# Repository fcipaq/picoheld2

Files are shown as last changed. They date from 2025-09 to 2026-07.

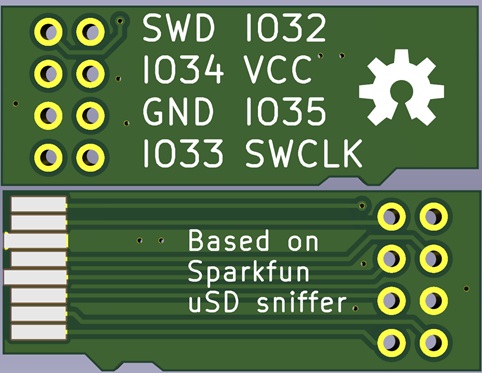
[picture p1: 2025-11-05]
pcb/rp2350/usd breakout board/uSD breakout board image.jpg

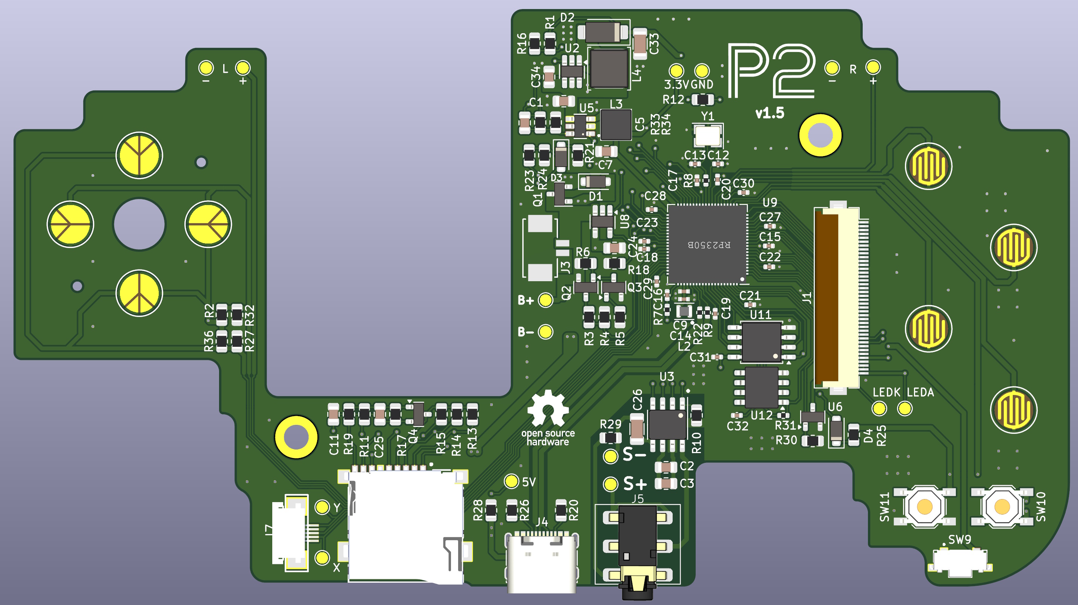
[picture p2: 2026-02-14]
pcb/rp2350/mainboard/p2_pcb_rp2350_v1_5_image.jpg

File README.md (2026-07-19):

# Pico Held 2 hardware resources

This site is all about the Pico Held 2's hardware: schematics, 3D design files, gerber files for PCB production, component specifications and so on.

DISCLAIMER: This is a DIY project. Do it at your own risk. I cannot be held responsible for anything that goes wrong, including design errors. I'm not doing this for profit – I'm just a guy sharing a hobby project.

## Obtaining the hardware as a kit

It's probably the cheapest solution if you buy everything as a bundle from me. I bought them in bulk to save on shipping costs. I sell a "kit" on eBay. It contains the mainboard (including the MCU), shoulder button PCBs, LCD, rubber pads, screws, speaker. However, you will still need the 3D-printed parts (case, start/select buttons, and shoulder buttons), the SNES buttons, the analog stick and the battery.
Since I'm not running a business and don't intend to, if you want to buy a kit, drop me an email (daniel.kammer@web.de) and I'll create an offer on eBay and send you the link (if I can ship to your country that is). The kit costs around 80 Euros.

## Notes on assembly

You can find an assembly video [here](https://www.youtube.com/watch?v=lgt-NjA-OhY).

Please watch the video to see if you are able to do it before making any purchases. Unfortunately, I cannot be held responsible if anything goes wrong. I'm not doing this for profit; I'm just a guy sharing a hobby project.

### parts

If you want to buy everything by yourself, you can find info/links about the parts here:

[LCD](https://aliexpress.com/item/1005007751423312.html) (ESP32-P4)

[LCD](https://aliexpress.com/item/1005008256444774.html) (RP2350)

[Speaker](https://aliexpress.com/item/1005004431389186.html)

For all other parts, see parts.txt in the assembly folder.

All parts for the PCB assembly can be found in the BOM lists in the pcb subfolder.

### 3D case

The 3D printed case features holding brackets for the LCD, holding the LCD tightly in place. Since the overall height has increased, you need to fiddle around a little bit with the rubber pads of the buttons (since the buttons are still the same height). You'll probably get the best results if you glue the rubber pads to the buttons so they won't slip. Tolerances are sometimes off, so using sandpaper may be necessary. There are threaded inserts for the screws required that you'll have to hammer innto the case. I can provide these in the kit, just let me know.
Using the printed version is at your own risk - I just do not have the resources to test is as thoroghly as I did with aluminum case. Since I did all the optimization for the aluminum shell, however, find the platic case to be more comfotable since it's a little thicker

## Software

For quick testing, the repos usually contain a folder called 'artifacts', which contains a file ready to be uploaded to the device.

### Flashing

To enter bootloader mode on both versions, do the following: Press SELECT (left key), then hold down START (right key). You can then release SELECT, but you need to keep START pressed. Releasing the START button will shut down the device and interrupt any ongoing data upload.
If anything goes wrong, you can always press the reset button (located behind the tiny hole on the bottom of the device) and start again.

### RP2350 version

[SNES emulator](https://github.com/fcipaq/picoheld2_rp2350_snes9x)

[Hardware engine](https://github.com/fcipaq/picoengine) (to create your own projects)

### ESP32-P4 version

[SNES emulator](https://github.com/fcipaq/snes9x_esp32)

[Quake](https://github.com/fcipaq/esp32-quake-p2)

[Retro-Go](https://github.com/fcipaq/esp32-quake-p2) (various retro emulators, WIP)

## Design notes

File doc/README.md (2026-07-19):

TODO

In case you want to pick a different display for the RP2350, be advised that some display are unable to change the gate driver scan direction so that the image will be flipped.

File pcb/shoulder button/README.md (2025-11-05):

This is the PCB for the shoulder buttons. You will (obviously) need two of them :)

The thickness is 1.6 mm

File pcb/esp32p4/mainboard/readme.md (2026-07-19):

These are the gerber files, schematics and BOM and CPL files for the mainboard (ESP32-P4 version)

!!! When manually installing the ESP32-P4-SOM, pay close attention to its orientation. Some versions have a dot imprint on the metal shell that can be misleading because it does NOT indicate pin 0.
IMPORTANT: The orientation of the SOM is correctly depicted in the image. Counterintuitively, the circular dent in the SOM's cover must not be aligned with the dot on the PCB (the SOM manufacturer may change that in the future)

The PCB thickness is 1.6 mm

The BOM and CPL files are in xlsx format ready to be manufactured at JLCPCB. I already checked the alignment. Unfortunately, some components are unavailable in JLC's parts library.

The JPG image is for reference only and might not accurately reflect the current state.

The battery connector (J3) is pretty tall, so depending on the tolerances, it might bump against the LCD. You might want to consider omitting the connector and solder the battery directly to the PCB.

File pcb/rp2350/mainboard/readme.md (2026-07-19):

These are the gerber files, schematics, BOM and CPL files for the mainboard (RP2350 version)

The battery connector (J3) is pretty tall, so depending on the tolerances, it might bump against the LCD. You might want to consider omitting the connector and solder the battery directly to the PCB.

The PCB thickness is 1.6mm

The BOM and CPL files come in two versions:

a) PCBWay
b) for JLCPCB (in an xlsx format). I already checked the alignment. Unfortunately, some components are unavailable in JLC's parts library.

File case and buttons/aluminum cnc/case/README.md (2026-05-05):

Be sure to upload the specifications for the threaded holes along with the particular step file for CNC machining.

It's advised to have both parts manufactured in one order so the manufacturer can check tolerances and fit the color of the top and bottom part.

Remarks for the manufacturer:
The top and bottom peaces are sub assemblies and will be screwed together
Laser mark: 
Units in mm
The laser mark is ONLY "P2" centered on the back of the shell. (The other lines are for dimensional reference only)
The lines must be filled (only the outline is shown). The blue area is what has to actually be laser marked.

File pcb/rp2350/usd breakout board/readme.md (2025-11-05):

These are the gerber files for the micro SD breakout board which you need if you want to break out the debug pins and/or (SPI-)GPIOs.

The PCB thickness is 0.8 mm

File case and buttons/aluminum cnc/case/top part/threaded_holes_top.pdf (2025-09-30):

Threaded Holes

Type A:

4 threads, M 1.6

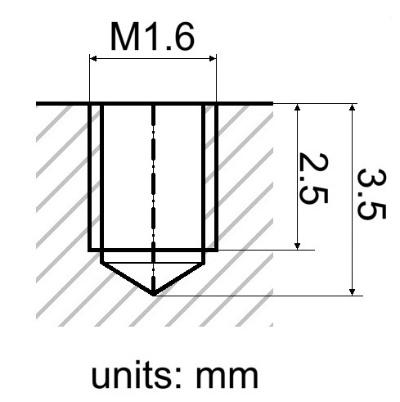
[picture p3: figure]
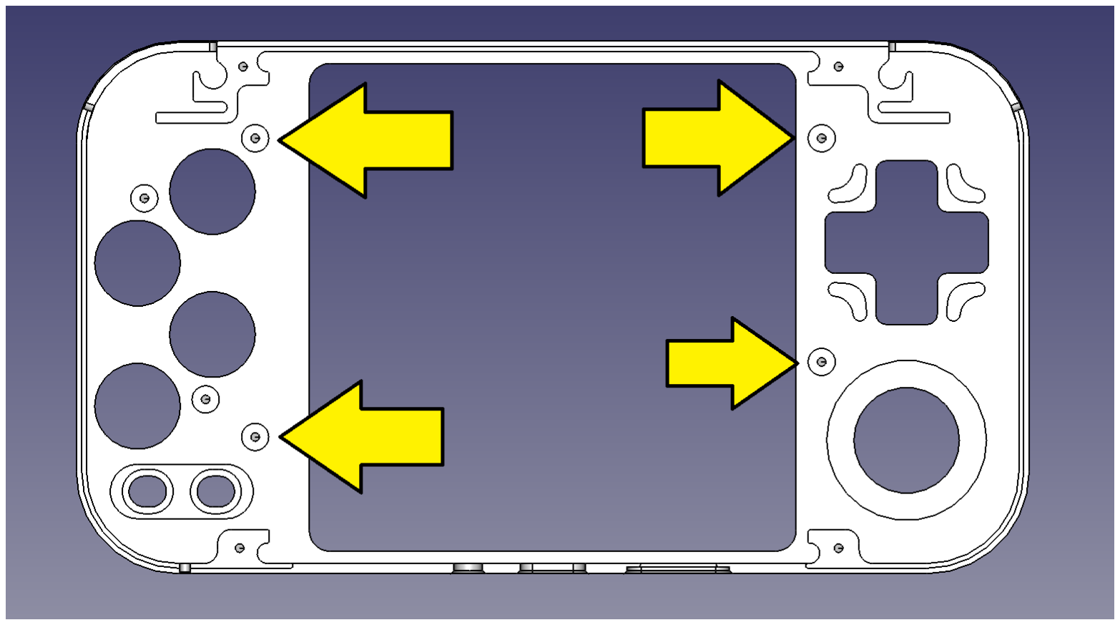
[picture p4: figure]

Type B:

4 threads, M1.6

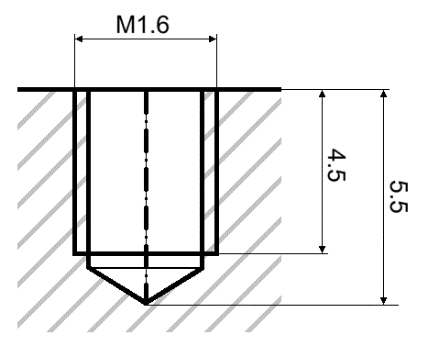
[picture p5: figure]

all units: mm

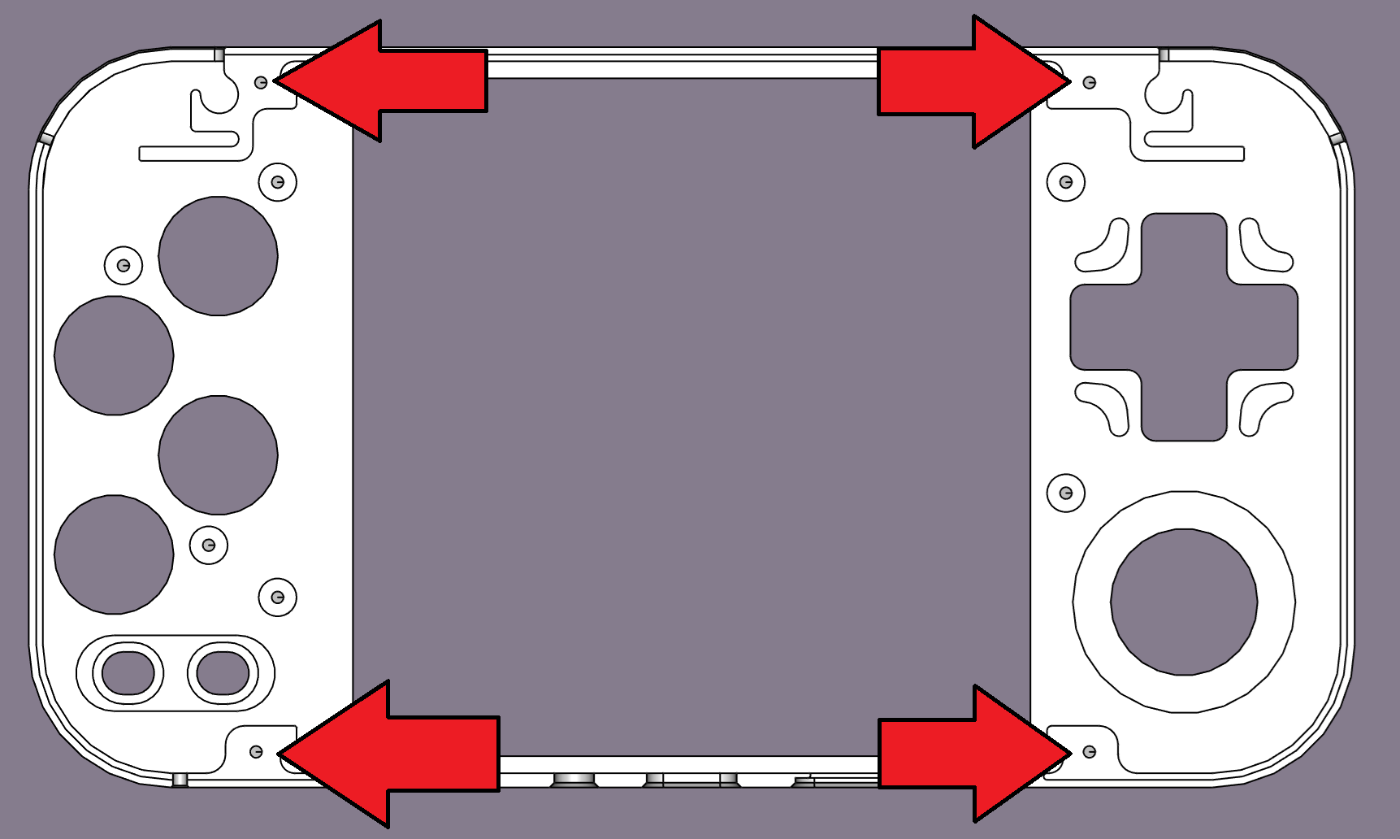
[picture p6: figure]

Type C:

2 threads, M1.6

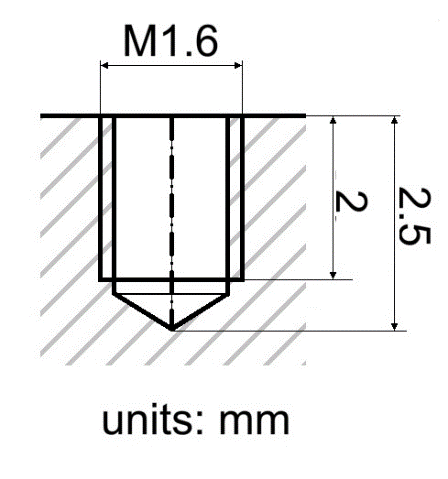
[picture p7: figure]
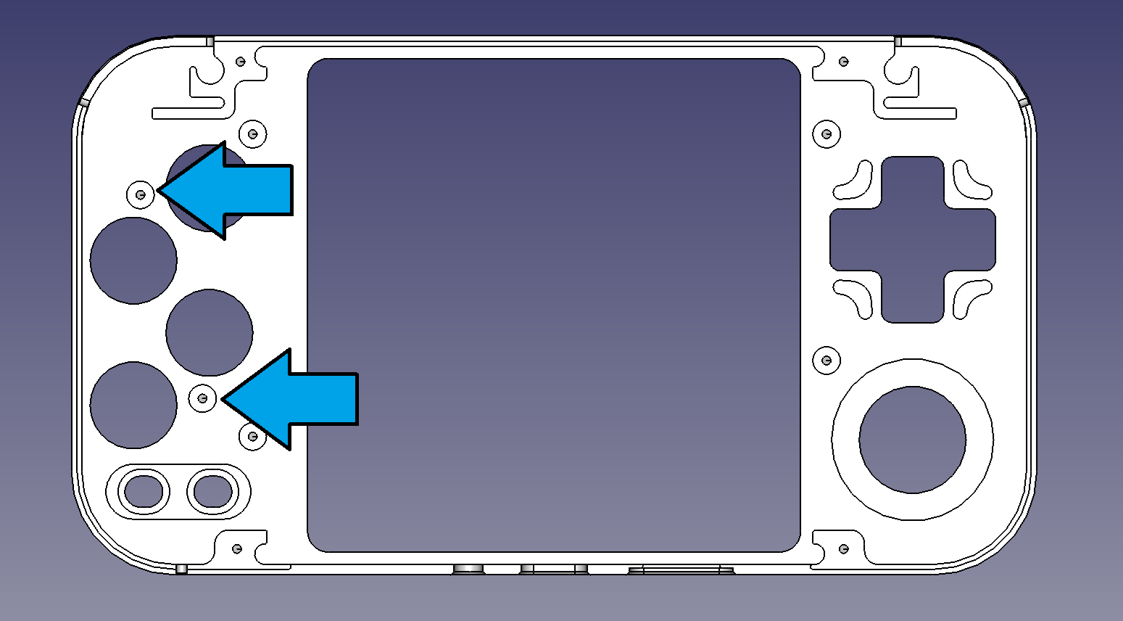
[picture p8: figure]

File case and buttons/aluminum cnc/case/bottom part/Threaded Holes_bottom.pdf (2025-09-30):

Threaded Holes

Type A:

2 threads, M 1.6

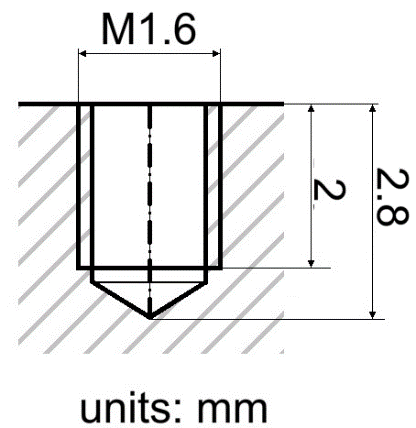
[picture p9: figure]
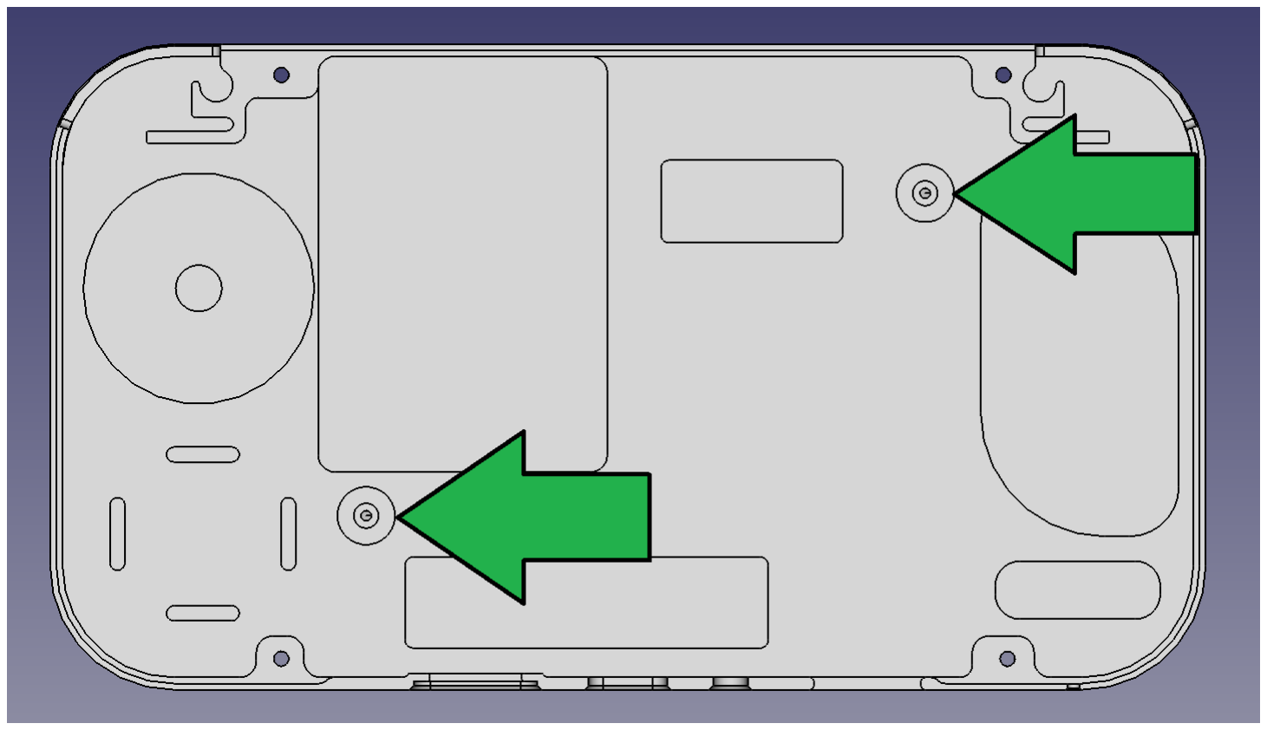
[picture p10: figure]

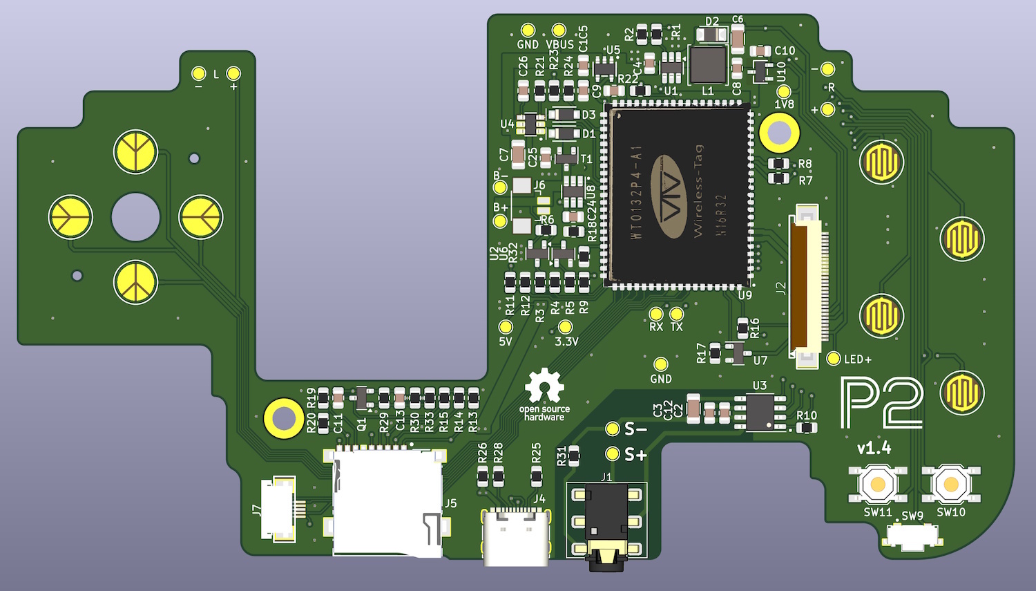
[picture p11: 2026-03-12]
pcb/esp32p4/mainboard/p2_pcb_esp32p4_v1_4_image.jpg

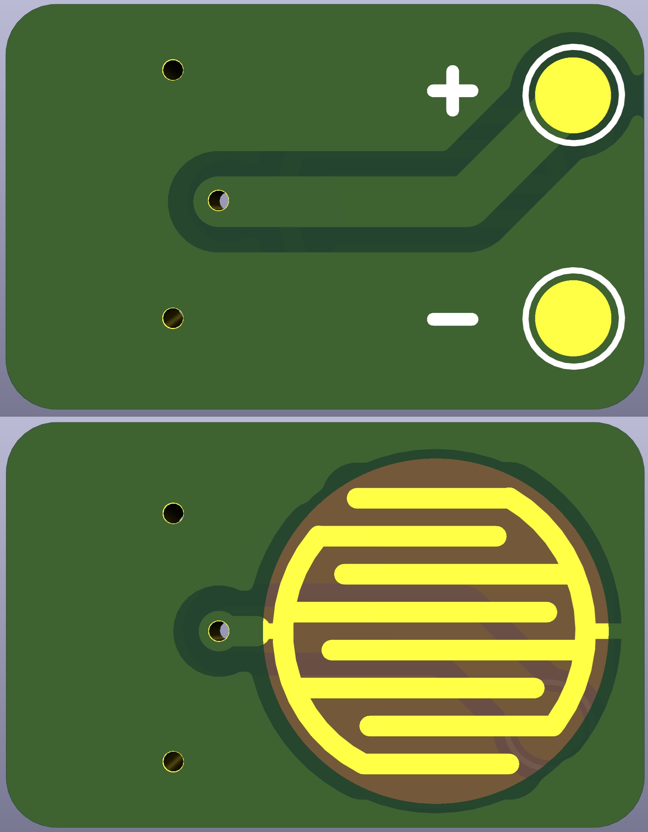
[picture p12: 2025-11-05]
pcb/shoulder button/shoulder_button_pcb_image.jpg

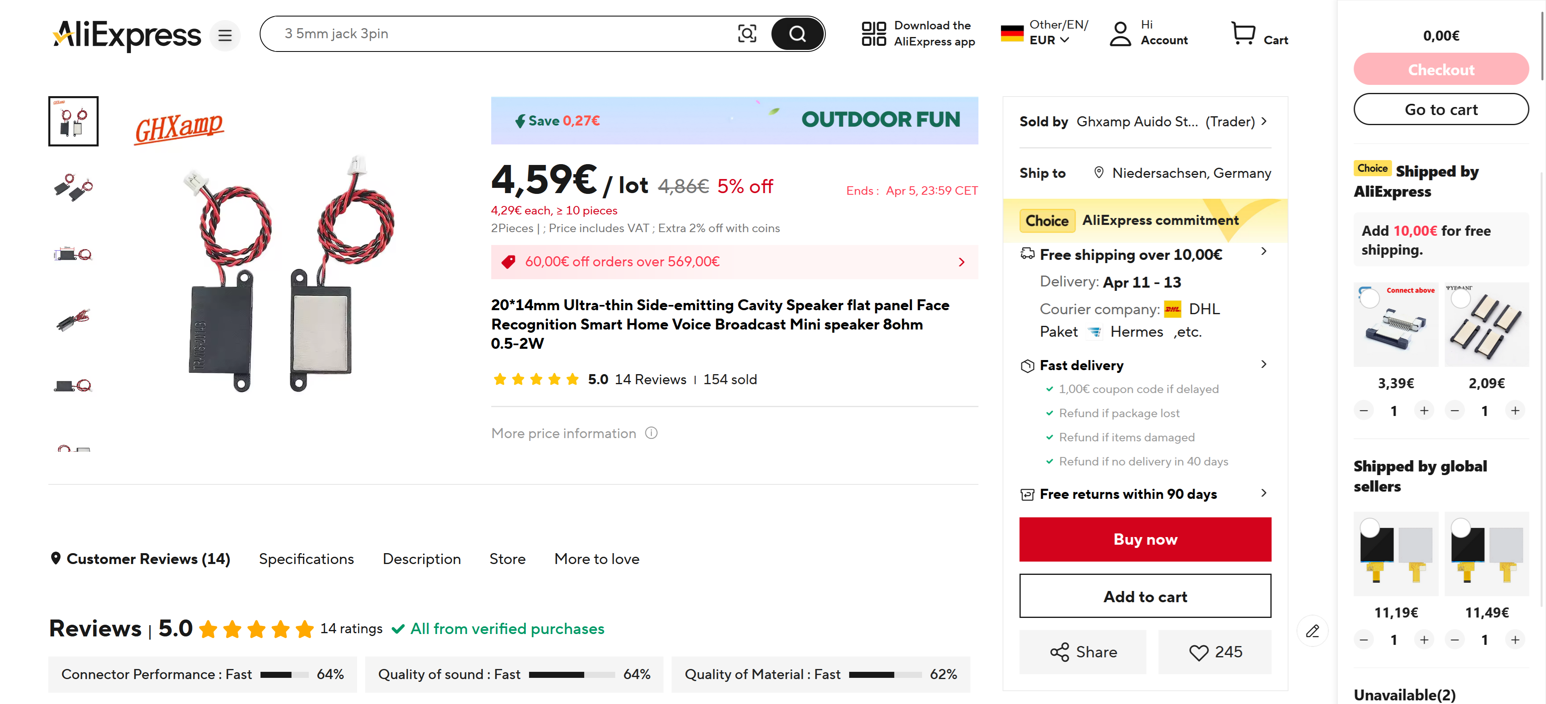
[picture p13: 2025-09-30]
datasheets/speaker/Untitled.png

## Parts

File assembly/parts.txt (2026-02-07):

Power:
  - Battery: li-po 3.7V, 603048 (width 30mm, thickness 6mm, length 48mm) (e.g. "Turtle Beach Stealth" battery)

Audio:
  - Speaker (see datasheets)

Buttons:
  - Switch Analog Stick (from the Switch 1, NOT 2)
  - 4 SNES buttons

Rubber pads:
  - DPAD: PS4 DPAD rubber pad
  - Buttons: PS4 ABXY rubber pad (need to be fitted)
  - Shoulder-Buttons: PS4 ABXY (need to be fitted)

PCBs:
  - 1x mainboard (obviously :) )
  - 2x Shoulder button PCB

Screws: 
  - case: 4 x M1.6 cone head, 8mm
  - button bearing: 2 x M1.6 cone head, 5mm
  - MB mounting: 2 x M1.6 cone head, 3mm
  - LCD mouting: currently not advised. The LCD is sitting properly and fast without screws.

3D printed components:
  - 1x d-pad
  - 2x shoulder button
  - 2x start/select button
  - 1x button bearing 3D
  
CNC machined parts:
  - case (top and bottom shell)

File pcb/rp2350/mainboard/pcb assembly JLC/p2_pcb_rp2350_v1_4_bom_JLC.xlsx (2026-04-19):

Comment | Designator | Footprint | JLCPCB Part # | Alternative
200k 1% | R1 | 0805 (2012 metric) | C17539
10k 1% | R2, R3, R4, R16, R27, R32, R36 | 0805 (2012 metric) | C17414
27R 1% | R9,R22 | 0402 (1005 metric) | C25100
120k 1% | R33 | 0805 (2012 metric) | C17436
27k 1% | R34 | 0805 (2012 metric) | C17593
10k | R10,R11,R13,R14,R15,R23,R25,R29,R30 | 0805 (2012 metric) | C17414
10k | R31 | 0402 (1005 metric) | C25744
100k | R5,R6,R28 | 0805 (2012 metric) | C25611
33R | R7 | 0402 (1005 metric) | C25105
1k | R8 | 0402 (1005 metric) | C11702
330R | R12 | 0805 (2012 metric) | C17630
100M | R17 | 0805 (2012 metric) | C53884
1.65k | R18 | 0805 (2012 metric) | C17393
20k 1% | R19,R24 | 0805 (2012 metric) | C4328
5.1k | R20,R26 | 0805 (2012 metric) | C26023
30k | R21 | 0805 (2012 metric) | C17621
4.7 uF | C1 | 0805 (2012 metric) | C1779
4.7 uF | C9, C14, C16, C17 | 0402 (1005 metric) | C23733
10 uF | C2, C7, C11, C34 | 0805 (2012 metric) | C1713
100 nF | C3,C25 | 0805 (2012 metric) | C28233
6.8 pF / 50 V | C5 | 0805 (2012 metric) | C318744
10 uF | C26, C33 | 1206 (3216 metric) | C13585
15 pF | C12, C13 | 0402 (1005 metric) | C86285
100 nF | C15,C18,C19,C20,C21,C22,C23,C27,C28,C29,C30,C31,C32 | 0402 (1005 metric) | C1525
1 uF | C24 | 0805 (2012 metric) | C1712
MBR120VLSFT1G | D1, D3, D4 | SOD-123F | C223608
SCHOTTKY DIODE SS24 2A 40V SMA SR240 DO-214AC | D2 | 1206 (3216 metric) | C50645
AOTA-B201610S3R3-101-T (3.3uH, RP2350 internal) | L2 |  | C42411119
XFL4020-222MEC (2.2uH 35mOhm, main buck) | L3 | 4020 | C122469
SWPA5020S3R3MT (3.3 uH, backlight boost) | L4 | 5020 | C86659 | C280582
DMG2305UX-7 | Q1 | SOT-23 | C5261054 | C150470
AO3401 | Q2 | SOT-23-3 | C15127
AO3402 | Q3,U6 | SOT-23-3 | C14385
FDN340P | Q4 | SOT-23 | C75469
SDB628 | U2 |  | C30197563
NS4168 | U3 |  | C910588
TLV62569PDDCR | U5 |  | C398365
TP4054 | U8 |  | C32574
RP2350B | U9 |  | C42415655
W25Q128JVSQ | U11 |  | C97521
APS6404L-3SQN-SN | U12 |  | C3028887 | C5333729 (3SQR)
ABM8-272-T3 | Y1 |  | C20625731
F-FPC0M40P-C310 | J1 |  | C132511
TF-01A | J2 |  | C2889258
GT-USB-7010ASV | J4 |  | C2988369
PJ-242 | J5 |  | C431536
GH 1.25 (LiPo connector) | J6 |  | C668614
AFC07-S05ECA-00 | J7 |  | C262578
TL3330AF260QG | SW9 |  | C410364 | C2886886
TL3342F260QG | SW10, SW11 |  | C92584

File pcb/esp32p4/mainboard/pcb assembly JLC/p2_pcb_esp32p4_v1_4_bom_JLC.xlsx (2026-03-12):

Comment | Designator | Footprint | JLCPCB Part #
150k 1% | R1 | R_0805_2012Metric | C17470
6.2k 1% | R2 | R_0805_2012Metric | C17767
33R 1% | R7,R8 | R_0805_2012Metric | C17634
10k 1% | R9,R3,R19,R13,R14,R16,R33,R15,R17,R20,R4,R22,R31 | R_0805_2012Metric | C17414
100k 1% | R12,R32,R10,R26,R11,R5,R6 | R_0805_2012Metric | C25611
1.65k 1% | R18 | R_0805_2012Metric | C17393
30k 1% | R21 | R_0805_2012Metric | C17621
100M | R29 | R_0805_2012Metric | C53884
5.1k 1% | R25,R28 | R_0805_2012Metric | C26023
20k 1% | R23,R24,R30 | R_0805_2012Metric | C4328
10uF 10% | C6,C3 | C_1206_3216Metric | C13585
10uF 10% | C11,C9,C2,C5,C4 | C_0805_2012Metric | C1713
22uF 10% | C7 | C_1206_3216Metric | C1859
1uF 10% | C8,C1,C10,C24,C25 | C_0805_2012Metric | C1712
NN | C26 | C_0805_2012Metric
100nF 10% | C13,C12 | C_0805_2012Metric | C28233
onsemi MBR120VLSFT1G | D3,D1 | SDO_SOD-123FL_ONS | C223608
MDD SS24 (SCHOTTKY DIODE SS24 2A 40V SMA SR240 DO-214AC) | D2 | D_1206_3216Metric | C50645
SWPA5020S3R3MT (3.3 uH, backlight boost) | L1 | 5020 | C86659 | C280582
Diodes Inc. DMG2305UX-7 | T1 | SOT-23 | C150470
onsemi FDN340P | Q1 | SOT-23 | C75469
MSKSEMI SDB628 | U1 | SOT-23-6_Handsoldering | C30197563
AO Semi AO3401 | U2 | SOT-23-3 | C15127
Shenzhen Nsiway Tech NS4168 | U3 | SOP-8_3.76x4.96mm_P1.27mm | C910588
TI TPS22810TDBVRQ1 | U4 | SOT95P280X145-6N | C2877634
Torex Semicon XC6220B331MR-G | U5 | SOT-25_TOR | C86534
AO Semi AO3402 | U7,U6 | SOT-23-3 | C14385
TOPPOWER TP4057-42-SOT26-R | U8 | SOT-23-6_Handsoldering | C12044
WT0132P4_SOM | U9 |  | C9900155824
Torex Semicon XC6206P182MR | U10 | SOT-23_TOR | C21659
SHOU HAN PJ-242 | J1 |  | C431536
Hirose FH12-30S-0.5SH(55) | J2 | FH12-30S-0.5SH | C506793
G-Switch GT-USB-7010ASV | J4 | USB_C_Receptacle_G-Switch_GT-USB-7010ASV | C2988369
Yuandi TF-01A | J5 | TF-01A | C2889258
GH 1.25 (LiPo connector) | J6 |  | C668614
Jushuo AFC07-S05ECC-00 | J7 | FH12-5S-0.5SH | C262230
E-Switch TL3330AF260QG | SW9 | SW_TL3330AF260QG | C2886886
E-Switch TL3342F260QG | SW10, SW11 | SW_SPST_TL3342 | C2886894 | C2886897

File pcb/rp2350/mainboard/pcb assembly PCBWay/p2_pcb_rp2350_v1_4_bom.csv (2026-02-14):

Item # | Designator | Quantity | Manufacturer | Mfg Part # | Descritption / Value | Package / Footprint | Type | Your Instructions / Notes
1 | R1 | 1 | generic 1% | 0805W8F2003T5E | 200k 1% | 0805 (2012 metric) | SMD | Please choose manufacturer freely
2 | R2, R3, R4, R16, R27, R32, R36 | 7 | generic 1% | RC0805FR-0710KL | 10k 1% | 0805 (2012 metric) | SMD | Please choose manufacturer freely
3 | R9,R22 | 2 | generic 1% | 0402WGF270JTCE | 27R 1% | 0402 (1005 metric) | SMD | Please choose manufacturer freely
4 | R33 | 1 | generic 1% | 0805W8F1203T5E | 120k 1% | 0805 (2012 metric) | SMD | Please choose manufacturer freely
5 | R34 | 1 | generic 1% | 0805W8F2702T5E | 27k 1% | 0805 (2012 metric) | SMD | Please choose manufacturer freely
6 | R10,R11,R13,R14,R15,R23,R25,R29,R30 | 9 | generic 5% | RC0805JR-0710KL | 10k | 0805 (2012 metric) | SMD | Please choose manufacturer freely
7 | R31 | 1 | generic 5% | RC0402JR-0710KL | 10k | 0402 (1005 metric) | SMD | Please choose manufacturer freely
8 | R5,R6,R28 | 3 | generic 5% | CQ05W8J0104T5E | 100k | 0805 (2012 metric) | SMD | Please choose manufacturer freely
9 | R7 | 1 | generic 5% | 0402WGJ0330TCE | 33R | 0402 (1005 metric) | SMD | Please choose manufacturer freely
10 | R8 | 1 | generic 5% | RC0402JR-071KL | 1k | 0402 (1005 metric) | SMD | Please choose manufacturer freely
11 | R12 | 1 | generic 5% | 0805W8J0331T5E | 330 | 0805 (2012 metric) | SMD | Please choose manufacturer freely
12 | R17 | 1 | generic 5% | 0805W8J0107T5E | 100M | 0805 (2012 metric) | SMD | Please choose manufacturer freely
13 | R18 | 1 | generic 5% | 0805W8F1651T5E | 1.65k | 0805 (2012 metric) | SMD | Please choose manufacturer freely
14 | R19,R24 | 1 | generic 5% | 0805W8J0203T5E | 20k | 0805 (2012 metric) | SMD | Please choose manufacturer freely
15 | R20,R26 | 2 | generic 5% | 0805W8J0512T5E | 5.1k | 0805 (2012 metric) | SMD | Please choose manufacturer freely
16 | R21 | 2 | generic 5% | RMCF0805JT30K0 | 30k | 0805 (2012 metric) | SMD | Please choose manufacturer freely
17 | C1 | 1 | generic 10% | CL21A475KAQNNNE | 4.7 uF | 0805 (2012 metric) | SMD | Please choose manufacturer freely
18 | C9, C14, C16, C17 | 4 | generic 10% | CL05A475KP5NRNC | 4.7 uF | 0402 (1005 metric) | SMD | Please choose manufacturer freely
19 | C2, C7, C11, C34 | 4 | generic 10% | GRM21BR61C106KE15L | 10 uF | 0805 (2012 metric) | SMD | Please choose manufacturer freely
20 | C3,C25 | 2 | generic 10% | 0805B104K250NT | 100 nF | 0805 (2012 metric) | SMD | Please choose manufacturer freely
21 | C5 | 1 | generic 10% | C0805C689K5GACTU | 6.8 pF / 50 V | 0805 (2012 metric) | SMD | Please choose manufacturer freely
22 | C26, C33 | 2 | generic 10% | 1206B106K100NT | 10 uF | 1206 (3216 metric) | SMD | Please choose manufacturer freely
23 | C12, C13 | 2 | generic 10% | TCC0402COG150K500AT | 15 pF | 0402 (1005 metric) | SMD | Please choose manufacturer freely
24 | C15,C18,C19,C20,C21,C22,C23,C27,C28,C29,C30,C31,C32 | 13 | generic 10% | 0402B104K160NT | 100 nF | 0402 (1005 metric) | SMD | Please choose manufacturer freely
25 | C24 | 1 | generic 10% | CC0805KKX7R9BB105 | 1 uF | 0805 (2012 metric) | SMD | Please choose manufacturer freely
26 | D1, D3, D4 | 3 | onsemi | MBR120VLSFT1G |  | SOD-123F | SMD | Please choose manufacturer freely
27 | D2 | 1 | generic | SCHOTTKY DIODE SS24 2A 40V SMA SR240 DO-214AC |  | 1206 (3216 metric) | SMD | Please choose manufacturer freely
28 | L2 | 1 | ABRACON | AOTA-B201610S3R3-101-T | 3.3uH |  | SMD | Rpi inductance for internal voltage regulator
29 | L3 | 1 | Coilcraft | XFL4020-222MEC | 2.2uH 35mOhm |  | SMD | May be replaced with compatible part, Main voltage regulator inductance
30 | L4 | 1 | Taiyo Yuden | NRS5030T3R3MMGJ | 3.3 uH |  | SMD | May be replaced with compatible part, Backlight boost inductance
31 | Q1 | 1 | Diodes Incorporated | DMG2305UX | DMG2305UX | SOT-23 | SMD
32 | Q2 | 1 | AOSMD | AO3401 | AO3401 | SOT-23-3 | SMD
33 | Q3,U6 | 2 | AOSMD | AO3402 | AO3402 | SOT-23-3 | SMD
34 | Q4 | 1 | onsemi | FDN340P | FDN340P | SOT-23 | SMD
35 | U2 | 1 | SHOUDING | SDB628 |  |  | SMD | Backlight booster switcher
36 | U3 | 1 | Nsiway | NS4168 |  |  | SMD | audio amp/codec
37 | U5 | 1 | TI | TLV62569PDDCR |  |  | SMD | Main voltage regulator switcher
38 | U8 | 1 | TOPPOWER | TP4057 |  |  | SMD | Lipo charger
39 | U9 | 1 | Raspberry Pi Ltd. | RP2350B |  |  | SMD
40 | U11 | 1 | Winbond | W25Q128JVSQ |  |  | SMD | Flash memory
41 | U12 | 1 | AP Memory | APS6404L-3SQR-SN |  |  | SMD | PSRAM
42 | Y1 | 1 | ABRACON | ABM8-272-T3 |  |  | SMD | Crystal
43 | J1 | 1 | Amphenol Aorora | F305-1A7H1-11040-E100 |  |  | SMD | May be replaced with compatible part, LCD connector
44 | J2 | 1 | Korean Hroparts Elec | TF-01A |  |  | SMD | May be replaced with compatible part, SD card holder
45 | J3 | 1 | DNF | DNF | DNF | DNF | SMD | Do not populate
46 | J4 | 1 | G-Switch | GT-USB-7010ASV |  |  | SMD | May be replaced with compatible part, USB port
47 | J5 | 1 | SHOU HAN | PJ-242 |  |  | SMD | May be replaced with compatible part, audio jack
48 | J7 | 1 | JUSHUO | AFC07-S05ECC-00 |  |  | SMD | May be replaced with compatible part, 0.5mm pitch, top contact
49 | SW9 | 1 | E-Switch | TL3330AF260QG |  |  | SMD | May be replaced with compatible part, reset switch
50 | SW10, SW11 | 2 | E-Switch | TL3342F260QG |  |  | SMD | May be replaced with compatible part, start button

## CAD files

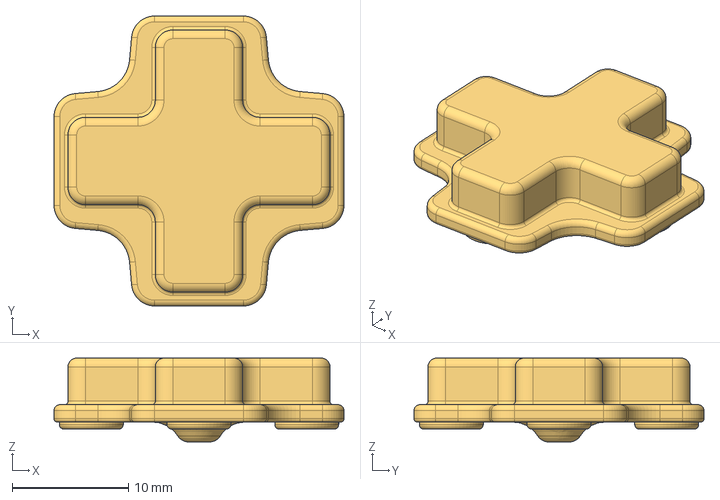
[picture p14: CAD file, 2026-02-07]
case and buttons/aluminum cnc/buttons/dpad_0.6mm_1.7mm.step
24.9 x 24.9 x 7.20 mm

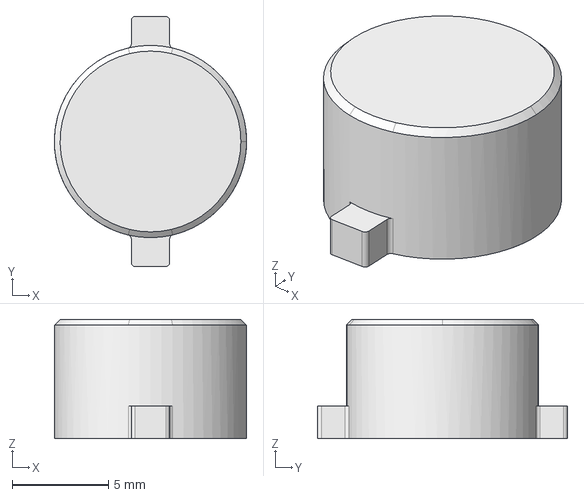
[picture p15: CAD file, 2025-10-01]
case and buttons/aluminum cnc/buttons/optional/abxy_button.step
10.00 x 13.0 x 6.20 mm

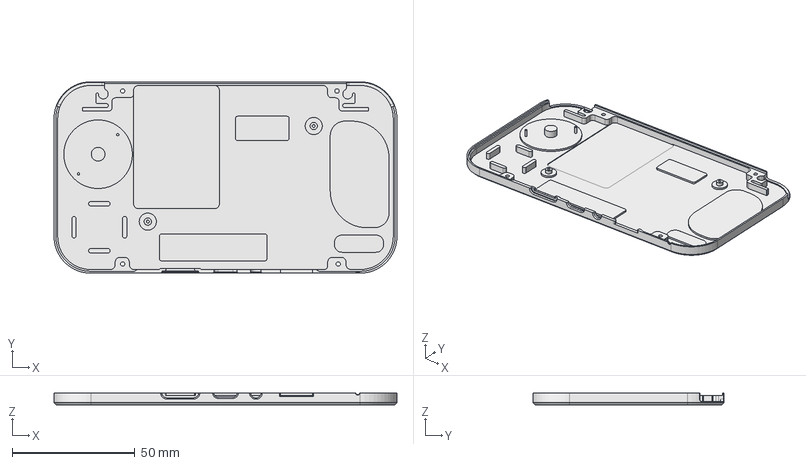
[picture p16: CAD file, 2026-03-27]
case and buttons/aluminum cnc/case/bottom part/case_bottom.step
139.9 x 78.1 x 5.00 mm

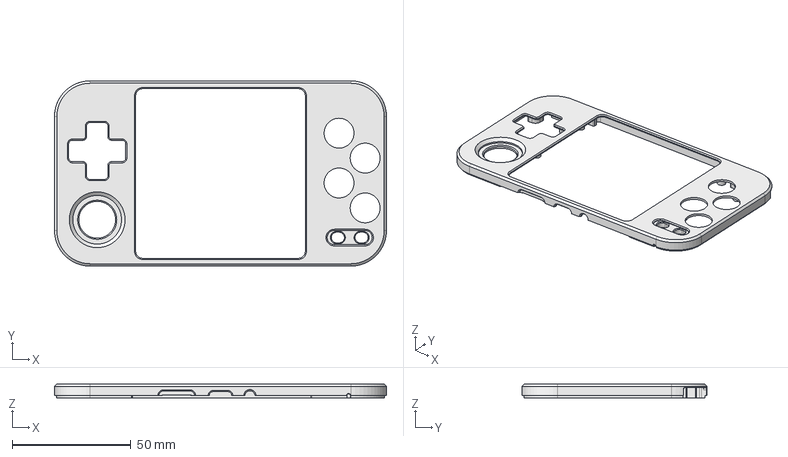
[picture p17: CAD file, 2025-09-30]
case and buttons/aluminum cnc/case/top part/case_top.step
140.0 x 78.1 x 6.00 mm

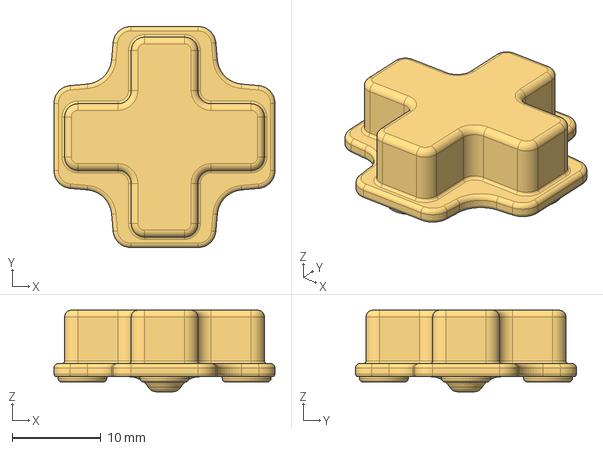
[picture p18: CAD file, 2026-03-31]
case and buttons/case 3d printed/buttons/dpad_6mm.step
24.9 x 24.9 x 9.20 mm

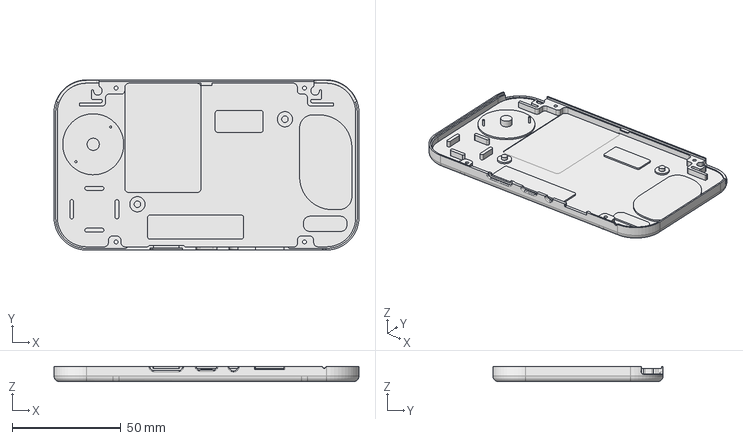
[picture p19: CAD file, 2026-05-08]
case and buttons/case 3d printed/case/case_bottom.step
139.9 x 78.1 x 7.00 mm

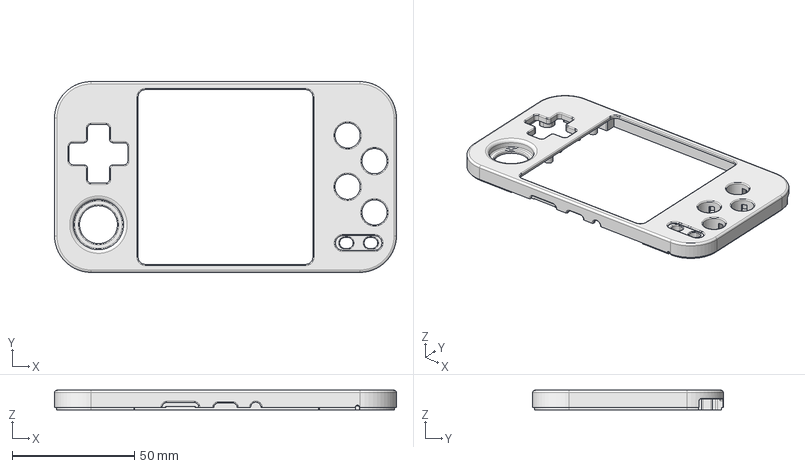
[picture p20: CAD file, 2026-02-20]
case and buttons/case 3d printed/top.step
140.0 x 78.1 x 8.00 mm

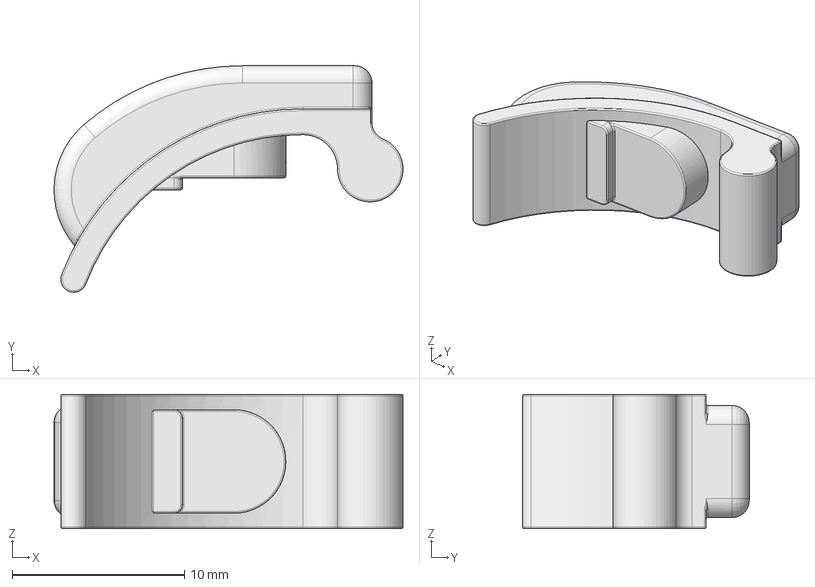
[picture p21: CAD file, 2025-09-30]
case and buttons/aluminum cnc/buttons/shoulder_button.step
20.2 x 13.1 x 7.80 mm

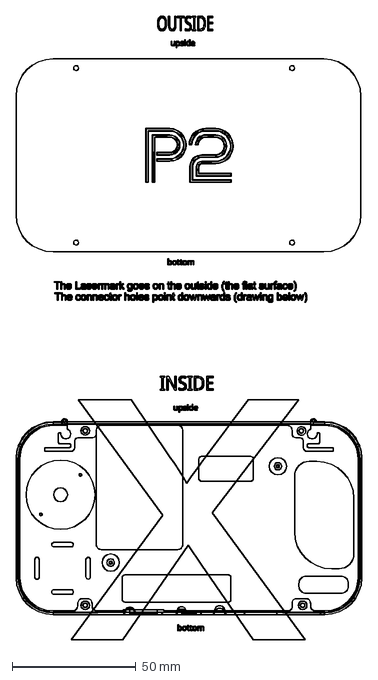
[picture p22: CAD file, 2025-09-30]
case and buttons/aluminum cnc/case/bottom part/drawing_laser_mark.dxf
139.9 x 252.5 mm

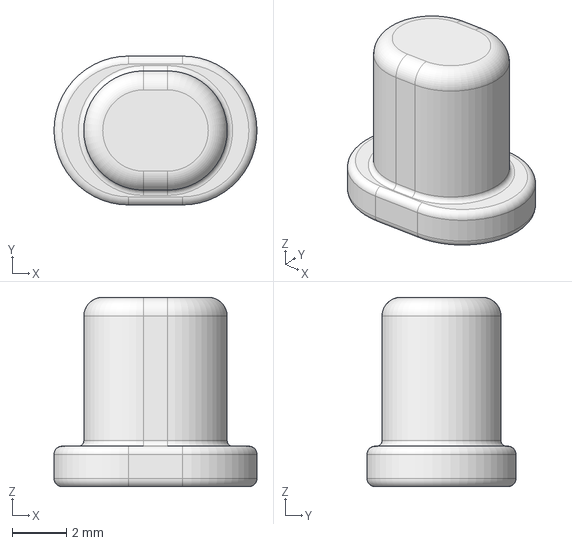
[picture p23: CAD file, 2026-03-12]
case and buttons/case 3d printed/buttons/start_select_button.step
7.50 x 5.50 x 7.00 mm

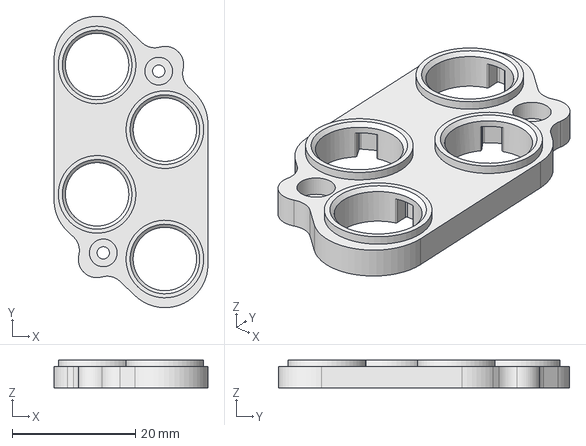
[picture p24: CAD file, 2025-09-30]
case and buttons/aluminum cnc/buttons/button_bearing.step
25.0 x 47.3 x 4.50 mm

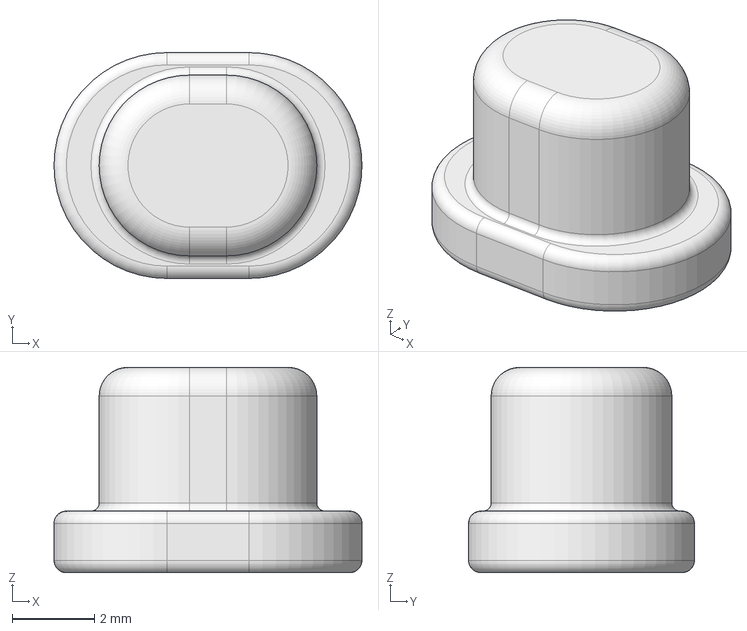
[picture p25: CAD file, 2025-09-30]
case and buttons/aluminum cnc/buttons/start_select_button.step
7.50 x 5.50 x 5.00 mm

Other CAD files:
case and buttons/buttons/dpad_03mm.step
case and buttons/case/bottom part/bottom.step
case and buttons/case 3d printed/case/case_top.step

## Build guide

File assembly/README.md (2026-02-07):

* Do not use screws that are too long. The thread extends 0.5 mm beneath the surface, so it's easy to damage it. Mind tolerances from the manufacturing process, if the screws don't fit easily, you might want to opt for a shorter screw (rather than damaging your case).
* The tolerances on the battery connector are very tight. This means that the connector might bump against the LCD, causing a stain to appear on the screen. Therefore, soldering the battery directly to the PCB is advised.

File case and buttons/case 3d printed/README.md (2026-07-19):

Please note that tolerances are pretty tight, depending on the printing technique. You may need to use sandpaper to rework some areas, especially the holes for the buttons. I had it printed at JLCPCB, and there were quite a few issues with warping. To mitigate this issue, I placed the part in hot water (70° C, be careful not to burn yourself) and pressed it flat. YMMV

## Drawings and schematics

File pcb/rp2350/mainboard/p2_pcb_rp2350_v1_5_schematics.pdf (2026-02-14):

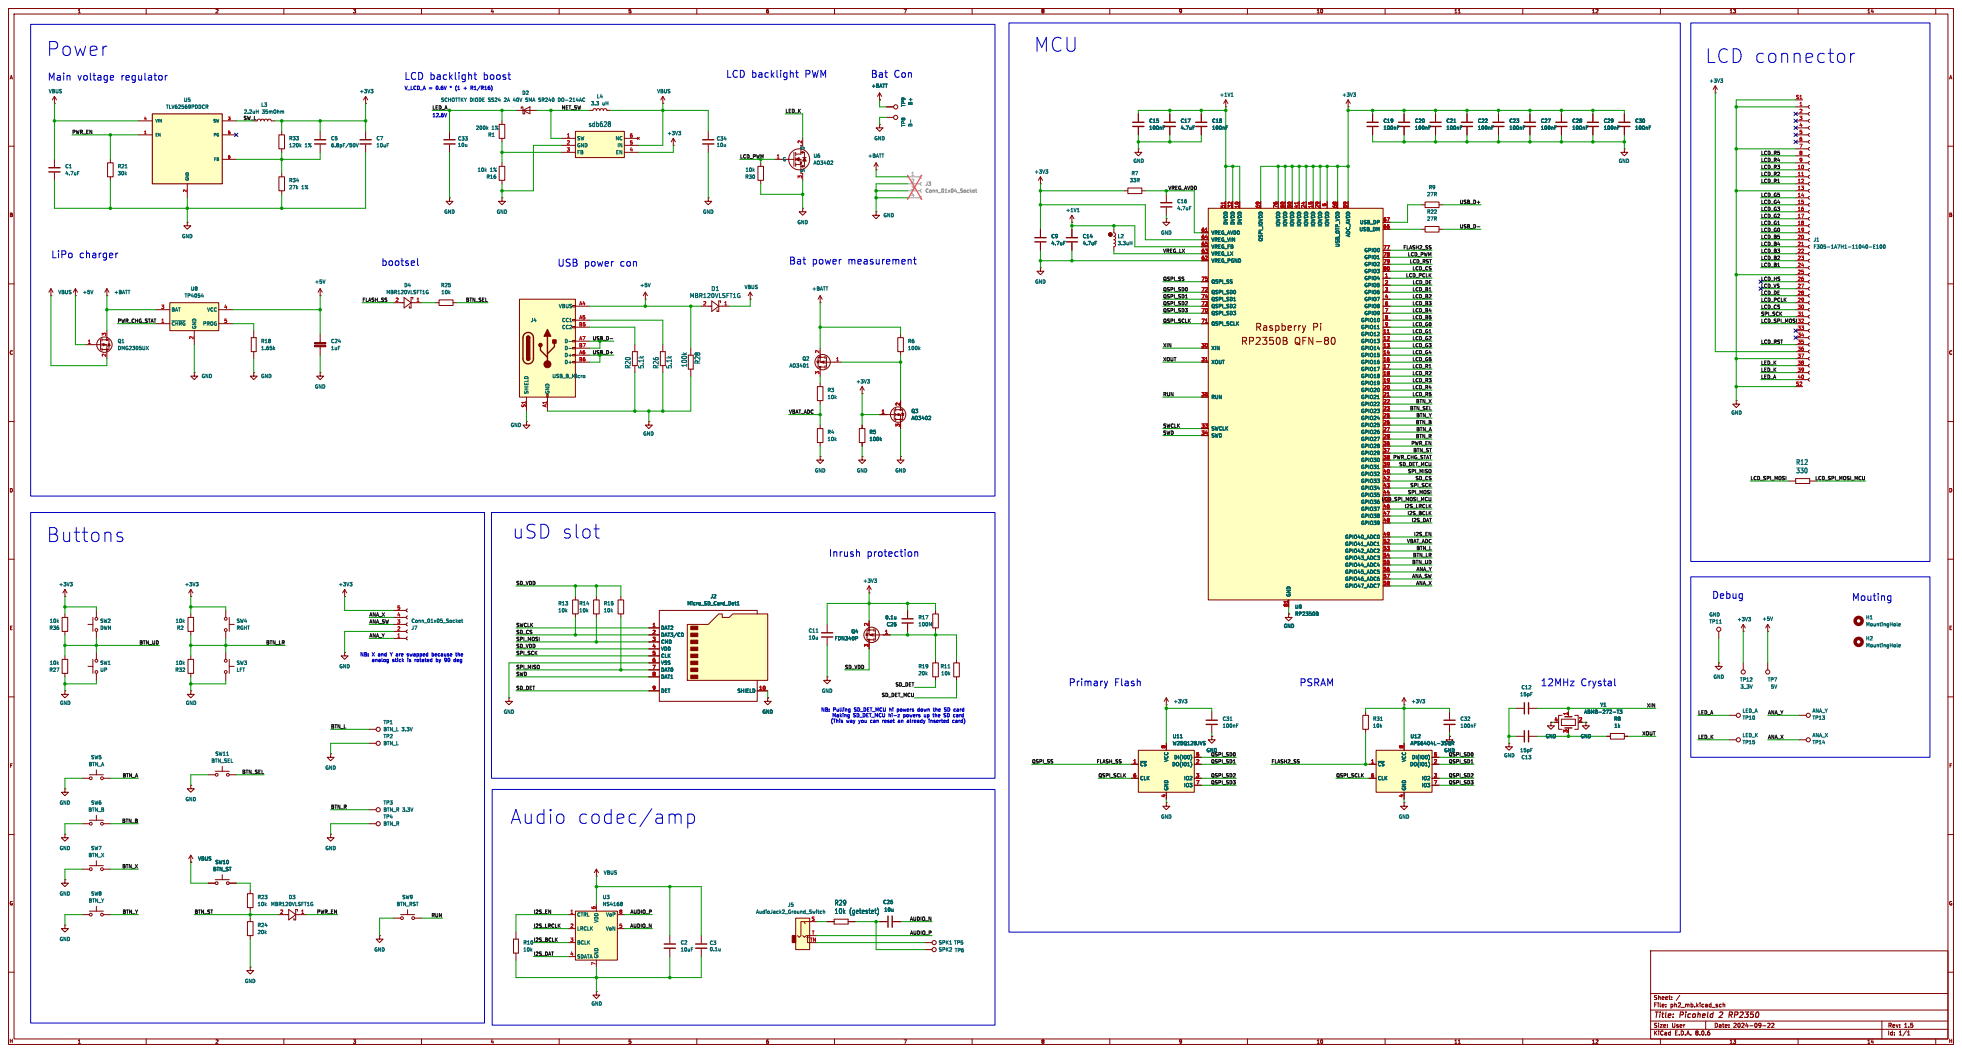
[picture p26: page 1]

D2 SCHOTTKY DIODE SS24 2A 40V SMA SR240 DO-214AC

2 SW 3 VIN 4 PG 5 FB 6 U5 TLV62569PDDCR

NB: X and Y are swapped because the
analog stick is rotated by 90 deg

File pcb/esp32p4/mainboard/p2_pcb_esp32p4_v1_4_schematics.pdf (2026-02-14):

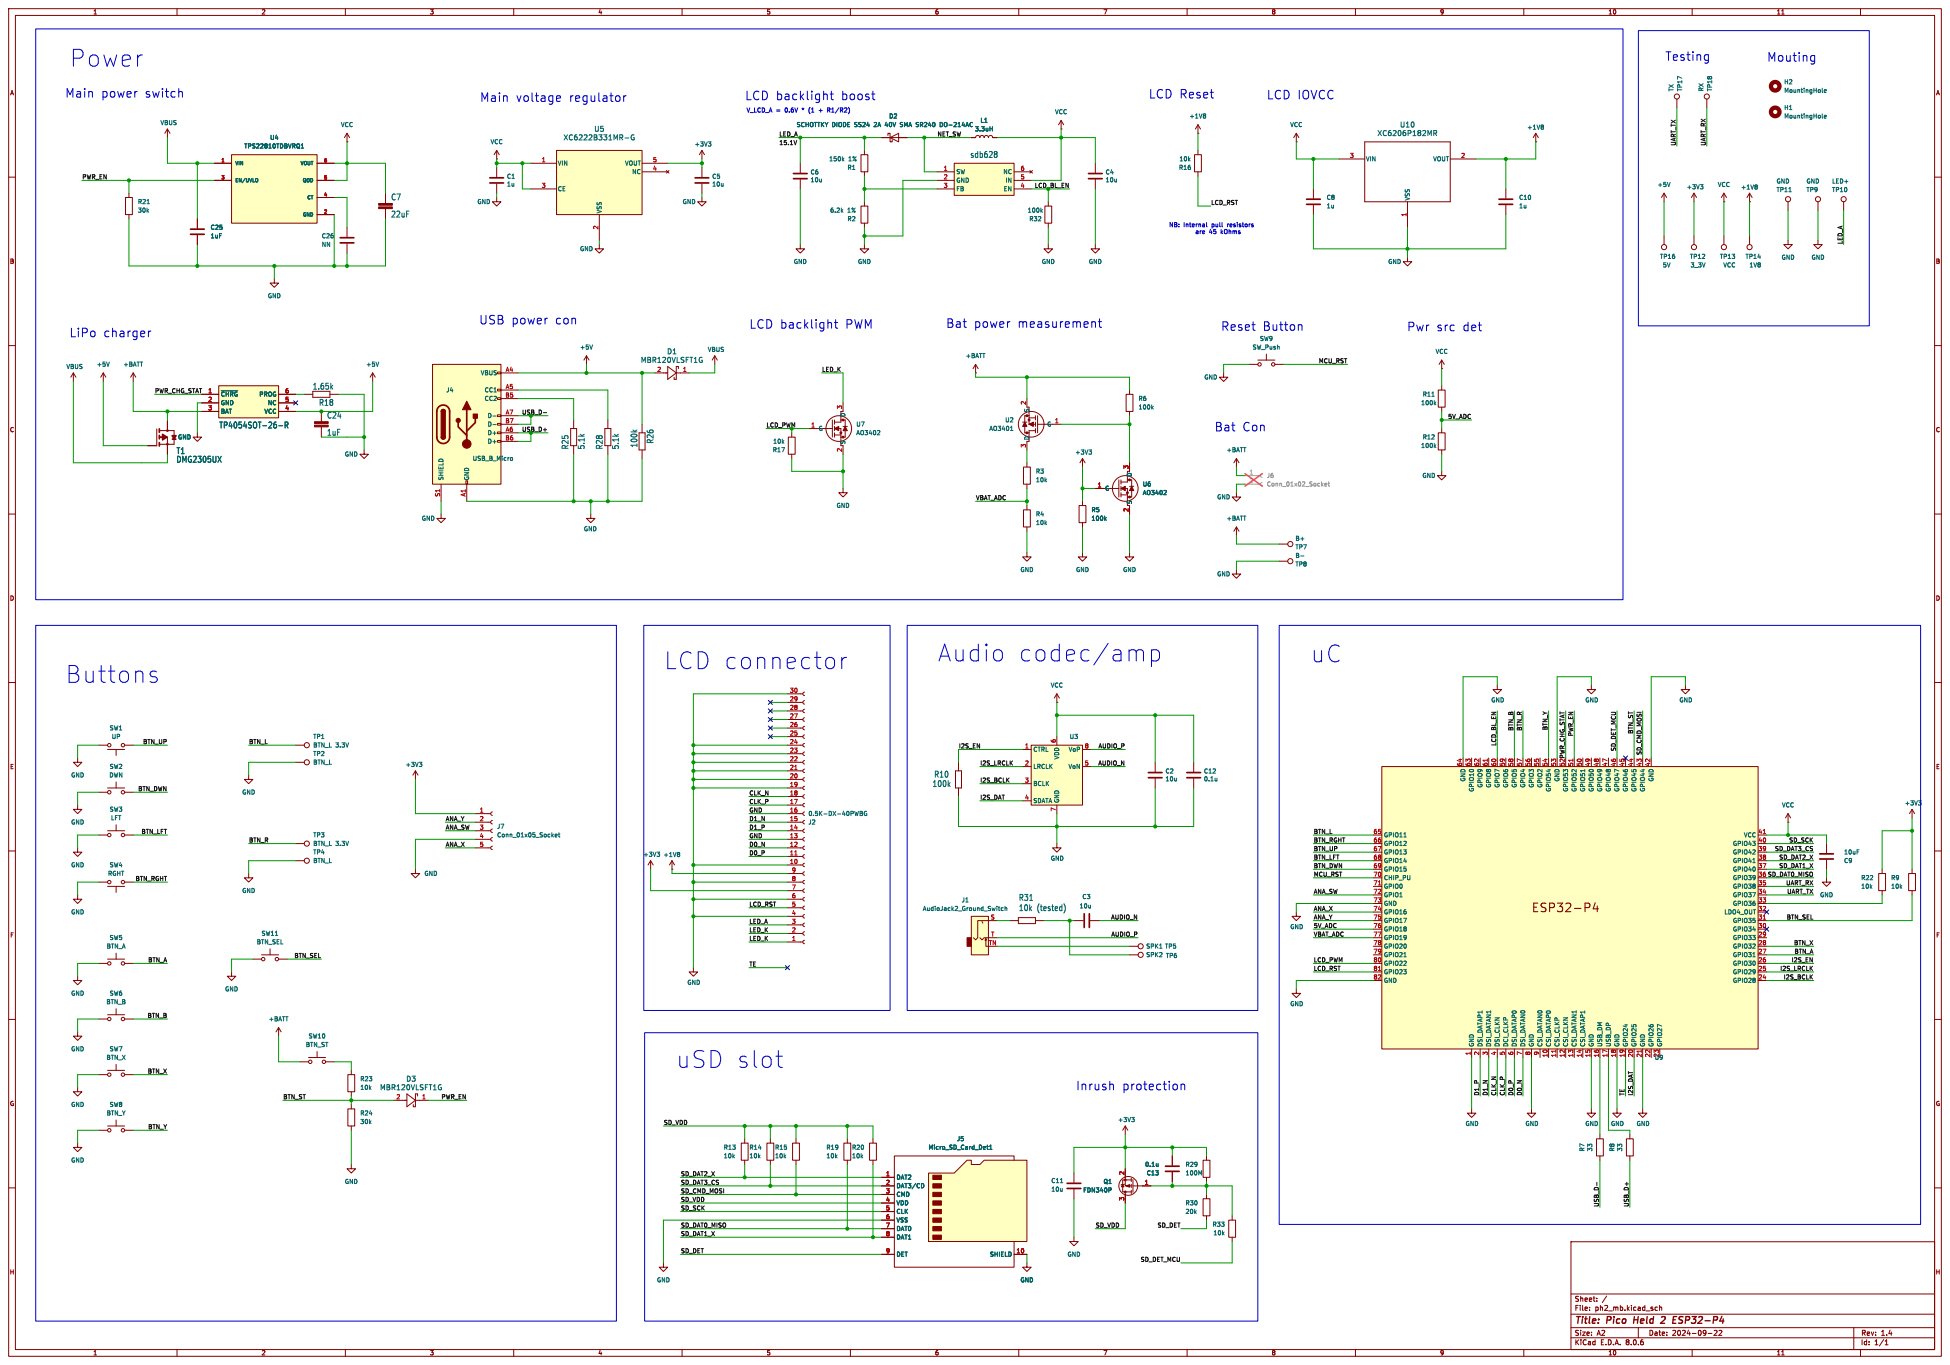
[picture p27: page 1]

D2 SCHOTTKY DIODE SS24 2A 40V SMA SR240 DO-214AC

D2 SCHOTTKY DIODE SS24 2A 40V SMA SR240 DO-214AC L1

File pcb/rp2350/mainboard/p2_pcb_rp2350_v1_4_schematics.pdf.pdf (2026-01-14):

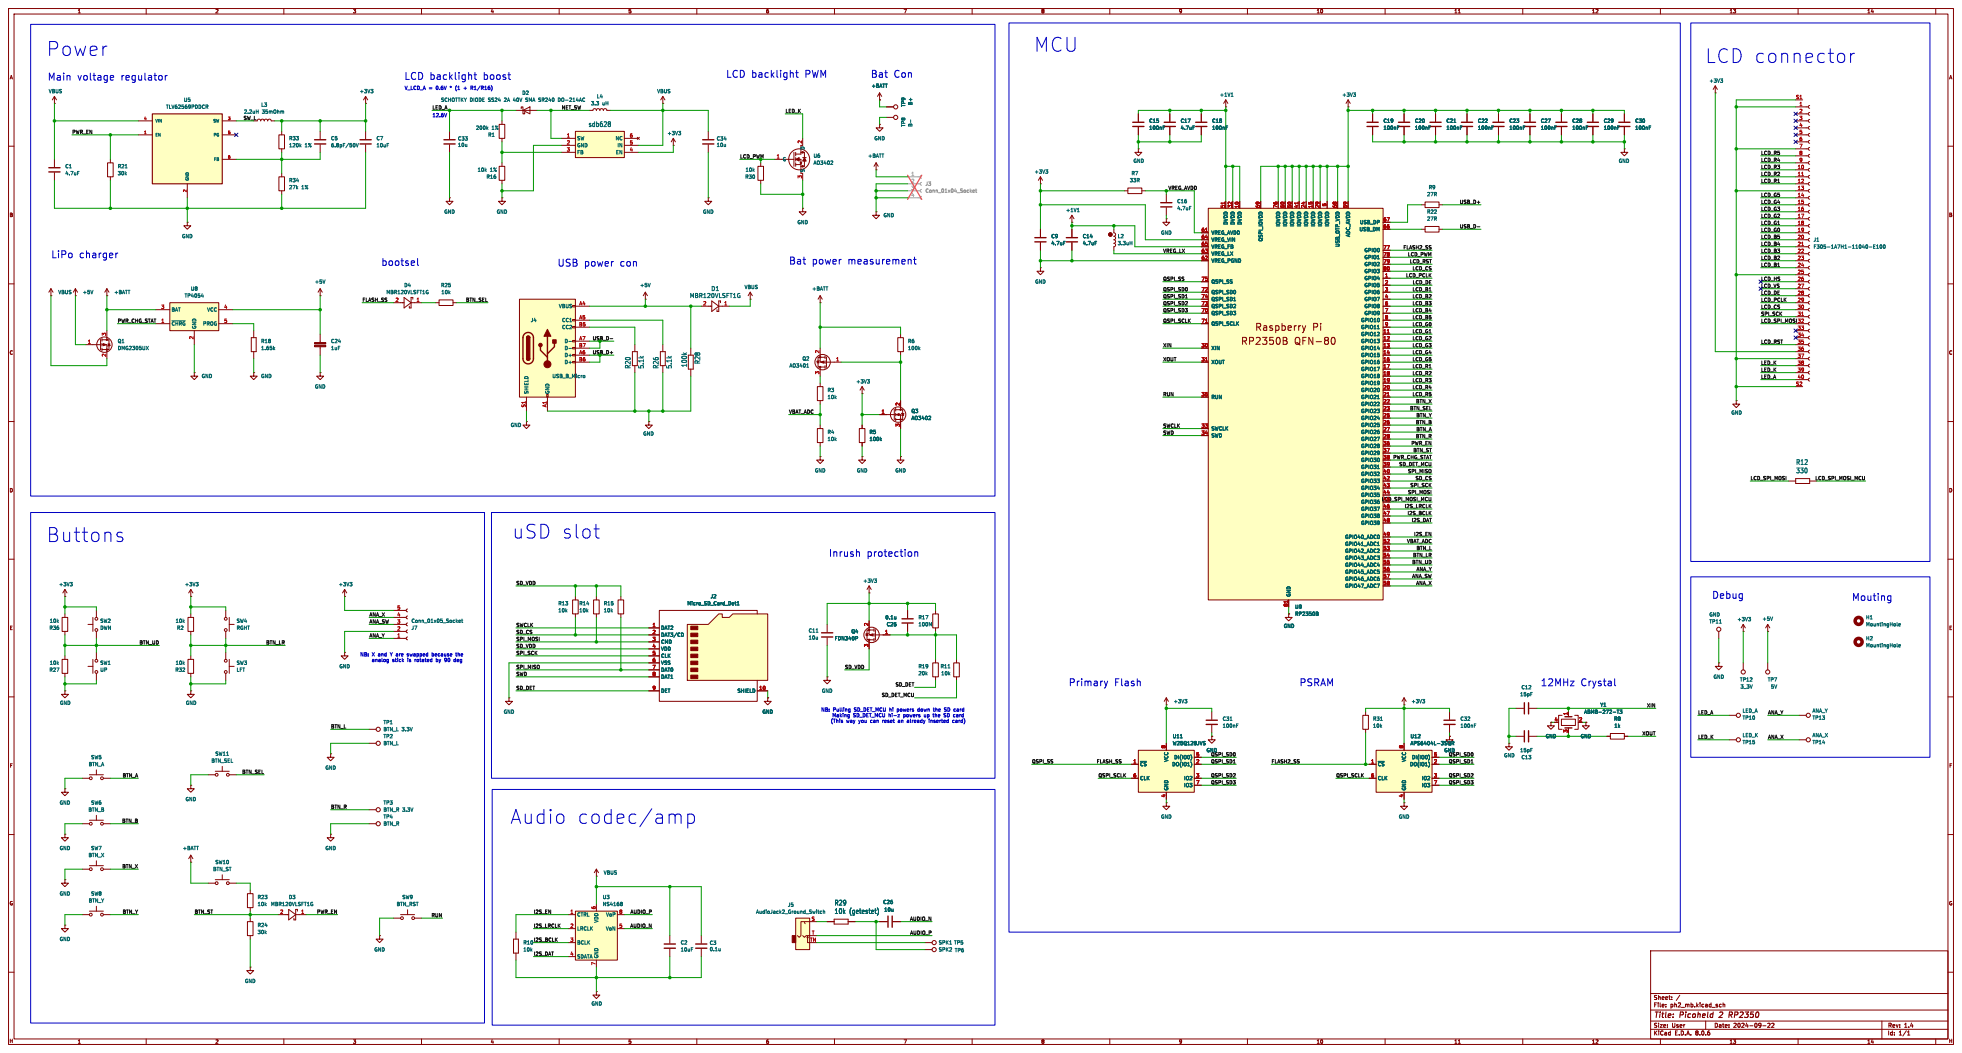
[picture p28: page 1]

2 SW 3 VIN 4 PG 5 FB 6 U5 TLV62569PDDCR GND

LCD_B1 NB: X and Y are swapped because the
FLASH_SS

analog stick is rotated by 90 deg

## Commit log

2025-09-30 Add some datasheets and the buttons 3D models
    [Button_bearing.step, HD395003C30工程图20231023(1).dwg, Shoulder_button.step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]
2025-10-01 a. Update shoulder button PCB; b. add button (for reference)
    [button.step]
2025-10-14 Update DPAD
    0.6mm is a little tighter. Better haptics but slightly more prone to false diagonals.
    [case_bottom.step, case_top.step, dpad_03mm.step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]
2025-10-15 Add P2 ESP32-P4 mainboard gerber files
2025-10-16 Update mainboard files, add uSD breakout board
2025-10-22 Update mainboard PCBs
2025-11-05 Updates to the PCBs, added PCB pictures, updates to some readme files
    [dpad_06mm.step, dpad_3d_printing.step, dpad_cnc.step]
2025-11-07 PCB ESP32-P4 fix LDO4 shorted to GND
    [HD395003C30.dwg, bom.csv]
2025-12-20 Updates (buttons and PCB)
    [bom.csv, dpad_0.15mm_1.2mm.step, dpad_3d_printing.step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]
2025-12-28 PCB notch for speaker cable passage
    [dpad_0.6mm_1.7mm.step]
2026-01-14 Fix tolerances analog stick
    [case_bottom.step]
2026-01-25 Create BOM for RP2350 version
    [p2_pcb_rp2350_v1_4_bom.csv]
2026-02-07 Add BOM and CPL files
    [p2_pcb_esp32p4_v1_4_bom_JLC.xlsx, p2_pcb_esp32p4_v1_4_pos_JLC.xlsx, p2_pcb_rp2350_v1_4_bom.csv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]
2026-02-07 Update some readmes and update dpad
    [dpad_0.15mm_1.2mm.step, dpad_0.6mm_1.7mm.step, dpad_0.6mm_1.7mm_old.step]
2026-02-14 Fix PSRAM footprint (RP2350)
    [p2_pcb_esp32p4_v1_4_bom_JLC.xlsx, p2_pcb_esp32p4_v1_4_pos_JLC.xlsx, p2_pcb_rp2350_v1_4_bom.csv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]
2026-02-14 Fix board cannot start without battery
    [p2_pcb_esp32p4_v1_4_bom_JLC.xlsx, p2_pcb_esp32p4_v1_4_pos_JLC.xlsx, p2_pcb_rp2350_v1_4_bom.csv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]
2026-02-20 Add case files for 3D printing (along with CNC)
    [bottom.step, case_bottom.step, case_top.step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]
2026-02-21 Fix inductor part (was too tall)
    [p2_pcb_esp32p4_v1_4_bom_JLC.xlsx, p2_pcb_esp32p4_v1_4_pos_JLC.xlsx, p2_pcb_rp2350_v1_4_bom_JLC.xlsx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]
2026-03-12 Update files for 3D printed case
    [abxy_button.step, bottom.step, button_bearing.step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]
2026-03-27 Update RP2350 USB plug
    [case_bottom.step, case_top_btn_1.5mm.step]
2026-03-27 Update RP2350 PCB(A) files
    [p2_pcb_rp2350_v1_4_bom_JLC.xlsx, p2_pcb_rp2350_v1_4_pos_JLC.xlsx]
2026-03-31 Update 3D printed files
    [case_top_btn_1.0mm_NEU_KNOPFLAGER.step, dpad_5mm.step, dpad_6mm.step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]
2026-04-02 Update case (revision required)
    [case_top_btn_1.0mm_DELME.step, case_top_btn_1.0mm_NEU_KNOPFLAGER.step]
2026-04-19 Fix wrong capacitor value in JLCPCB BOM
    [case_top_btn_1.0mm_NEU_KNOPFLAGER_2.step, case_top_btn_1.0mm_NEU_KNOPFLAGER_DELME.step, p2_pcb_rp2350_v1_4_bom_JLC.xlsx]
2026-05-05 Update STEP files
    [abxy_button.step, case_top.step, case_top_btn_1.0mm_DELME.step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]
2026-05-08 Add PCB holding bracket for 3D printed case
    [case_bottom.step]
